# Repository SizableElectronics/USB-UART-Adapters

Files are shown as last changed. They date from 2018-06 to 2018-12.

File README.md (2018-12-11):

# USB-UART-Adapters
We started our UART adapters project because we needed a good insolated adapter. It's somewhat uncommon and not cheap. Time to change that. Check out [sizableelectronics.com/uart-adapters](https://sizableelectronics.com/uart-adapters) for more information. All projekt files and schematics are open source under the **Apache License Version 3.0**.

## Common features of all 3 adapters
* Uses the CP2102 usb to serial ic. Driver is usually not needed on Windows 7/8/10, Mac OS X and Linux.
* All adapters comes with the standard FTDI order of pins on the serial side of the adapter. `GND, NC, VCC, TXD, RXD and NC`. The colors will also match. This layout is the most used layout. But not everyone uses it, please check your layout before pluggin anything in to prevent burning boards.
* All adapters uses the new USB type C connector. Futureprooofness. A type-C to type-A cable is included in the box.

## Short info about the adapters
There are going to exist three different UART adapters in out serie. This is some short info about the induviual adapters below. For more info, check out their's appropriate folders.

* **Serial Dog**
A normal USB to UART/Serial adapter. Delivers 3.3v power to target.

* **Serial Fox**
A USB to UART/Serial adapter that have a wide input range. Both 3.3V and 5V will work. The name Serial Fox comes from the fact that a Fox is very agile, almost like this adapter with the context of voltage levels.

* **Serial Hopper**
A fully insolated USB to UART/Serial adapter. Protects the target from the computer and the other way around in case something bad would to happen to any on them. The name Serial Hopper comes from the fact that a grasshopper jumps really long. Almost like the insolated signals going through the adapter.

## A comparison between the adapters
Serial Dog | Serial Fox | Serial Hopper
--- | --- | ---
USB 2.0 (12 Mbps) | USB 2.0 (12 Mbps) | USB 2.0 (12 Mbps)
USB powers target | Needs power from both ends | Needs power from both ends
3.3V Target levels | 2-6V Target levels | 3.3 or 5v Target levels
Not insulated | Voltlevel insulation | Fully electric insulation
Target Price $11.9 | Target Price $11.9 | Target Price $16.9

## License
Apache License Version 3.0

## Typical BOM
Amount | Part | Description | Pad(s) | Datasheet | Buy Link
--- | --- | --- | --- | --- | ---
1 | CP2102N-A01-GQFN28 | USB to UART IC | U1 | [Github](https://github.com/SizableElectronics/USB-UART-Adapters/raw/master/datasheets/cp2102.pdf) | [LCSC](https://lcsc.com/product-detail/USB_SILICON-LABS_CP2102N-A01-GQFN28_CP2102N-A01-GQFN28_C105167.html) [Digikey](https://www.digikey.se/product-detail/en/silicon-labs/CP2102N-A01-GQFN28/336-3694-ND/6012519)
1 | TYPE-C-31-M-12 | USB Type-C connector | CN1 | -- | [Aliexpress](https://www.aliexpress.com/item/100PCS-LOT-USB-connector-Type-C-3-1-Female-connector-16Pin-SMD-SMT-Type-with-4/32822609480.html) [LCSC](https://lcsc.com/product-detail/USB-Type-C_TYPE-C-31-M-12-Female-16P-SMD_C165948.html)
1 | 1x6 Header | 6-pin, angled, 2.54mm/0.1", smd, female | C1 | -- | [Alibaba](https://www.alibaba.com/product-detail/SMD-0-1-Right-Angle-6_60556277672.html)
1 | USBLC6-2SC6 | USB Protection IC | D1 | -- | [Digikey](https://www.digikey.se/product-detail/en/stmicroelectronics/USBLC6-2SC6/497-5235-1-ND/1121688)
1 | AZ1117H-3.3TRG1  | LDO, Stepdowns for 3V3 | U2 | [Github](https://github.com/SizableElectronics/USB-UART-Adapters/raw/master/datasheets/AZ1117-1139752.pdf) | [Mouser](https://www.mouser.se/ProductDetail/Diodes-Incorporated/AZ1117H-33TRG1?qs=5V6w%252be2aIqa3gA4GjxrsQQ==) [LCSC](https://lcsc.com/product-detail/Low-Dropout-Regulators-LDO_DIODES_AZ1117H-3-3TRG1_AZ1117H-3-3TRG1_C110474.html)
2 | BAT54S | Target protection diods | D2, D3 | -- | [LCSC](https://lcsc.com/product-detail/Schottky-Barrier-Diodes-SBD_NXP_BAT54S_BAT54S-215_C47546.html)
6 | 22R Resistor | 0402 | R1,R2,R5,R6,R7,R8 | -- | [LCSC](https://lcsc.com/product-detail/Chip-Resistor-Surface-Mount_22R-220-5_C93929.html)
1 | 47k5 Resistor | 0402, for config of CP2102N | R3 | -- | [LCSC](https://lcsc.com/product-detail/Chip-Resistor-Surface-Mount-UniOhm_Uniroyal-Elec-0402WGF4752TCE_C25896.html)
1 | 22k1 Resistor | 0402, for config of CP2102N | R4 | -- | [LCSC](https://lcsc.com/product-detail/Chip-Resistor-Surface-Mount-UniOhm_Uniroyal-Elec-0402WGF2212TCE_C43473.html)
3 | 680R Resistor | 0402 | R9,R10,R11 | -- | [LCSC](https://lcsc.com/product-detail/Chip-Resistor-Surface-Mount-UniOhm_Uniroyal-Elec-0402WGJ0681TCE_C25177.html)
1 | 3K3 Resistor  | 0402 | R12 | -- | [LCSC](https://lcsc.com/product-detail/Chip-Resistor-Surface-Mount_3-3KR-332-5_C102983.html)
4 | 100n Capacitor | 0402 | C2,C3,C4,C5 | -- | [LCSC](https://lcsc.com/product-detail/Multilayer-Ceramic-Capacitors-MLCC-SMD-SMT_muRata_GCM155R71C104KA55D_100nF-104-10-16V-Car-level_C85857.html)
1 | 10u Capacitor | 0603 | C6 | -- | [LCSC](https://lcsc.com/product-detail/Multilayer-Ceramic-Capacitors-MLCC-SMD-SMT_10uF-106-20-16V_C109457.html)
1 | 600Ω Inductor | 0603 | L1 | -- | [LCSC](https://lcsc.com/product-detail/Ferrite-Beads-And-Chips_600R-25-1-3A_C97000.html)
1 | Polyfuse | 1206 | F1 | -- | [LCSC](https://lcsc.com/product-detail/Surface-Mount-Fuses_Self-healing-fuse-500mA-15V_C146252.html)
1 | ORANGE LED | TX LED 0603 | D4 | -- | [LCSC](https://lcsc.com/product-detail/_FFC-1608YOXK-600H08_C108553.html)
1 | GREEN LED | POWER LED 0603 | D5 | -- | [LCSC](https://lcsc.com/product-detail/Light-Emitting-Diodes-LED_Emerald-SMDLED-500-1080mcd_C87326.html)
1 | YELLOW LED | RX LED 0603 | D6 | -- | [LCSC](https://lcsc.com/product-detail/_FC-1608YXK-585F08_C89811.html)

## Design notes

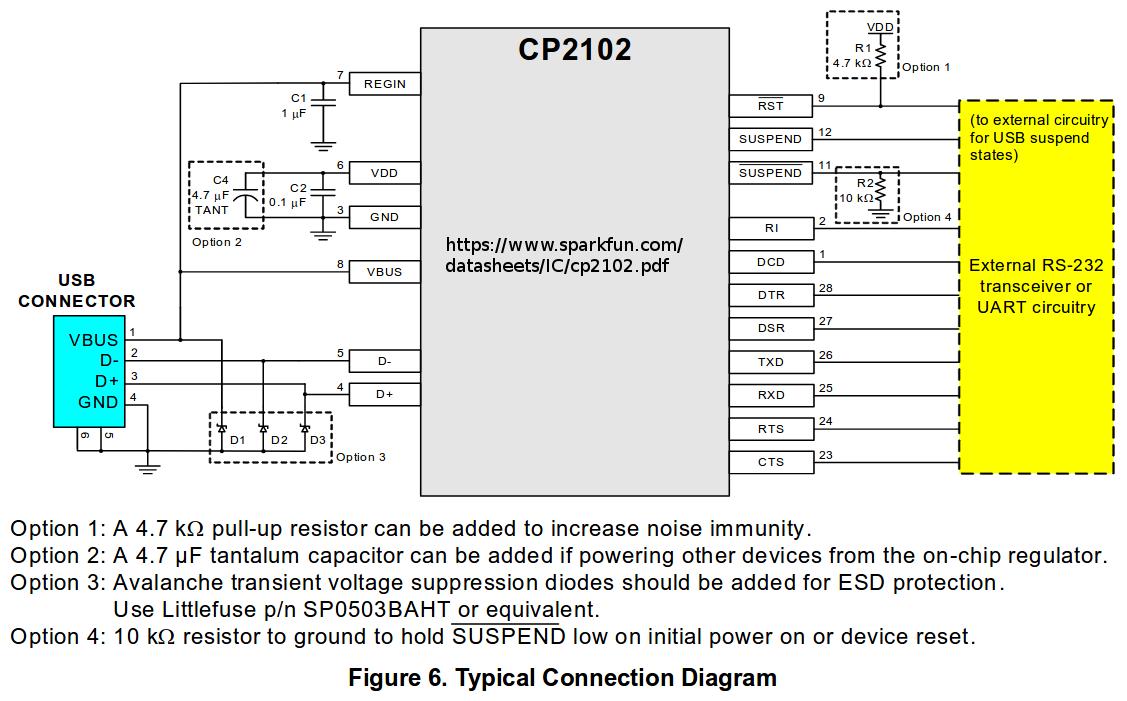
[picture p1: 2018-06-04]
datasheets/cp2102_appl_sch.png

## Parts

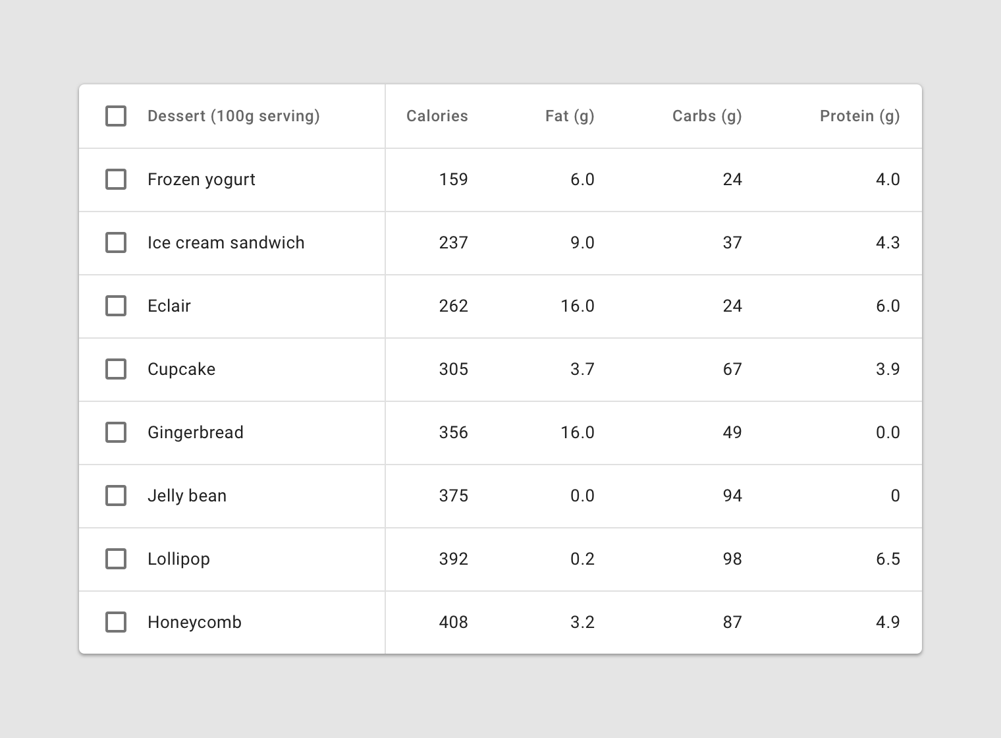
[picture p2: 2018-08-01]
datasheets/components-datatables-structure.png

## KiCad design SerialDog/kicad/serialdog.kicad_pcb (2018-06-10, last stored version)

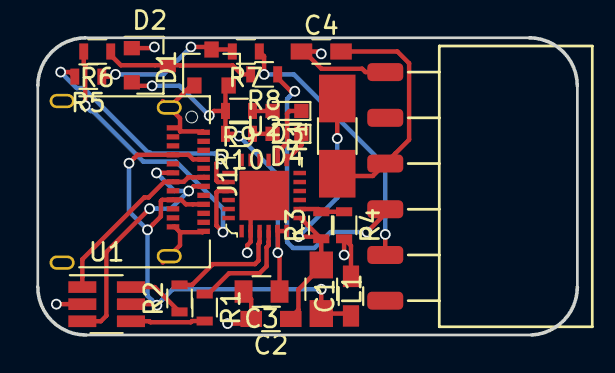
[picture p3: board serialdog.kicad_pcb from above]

Board: 2 copper layers, 30.0 x 16.5 mm, 24 parts (0 on the bottom side), 22 nets.

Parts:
C1, C2, C4: 1u; R_0603_HandSoldering
C3: 1u; C_0805
D1, D2: BAT54S; SOT-23
D3, D4: LED; LED_0603
F1: Polyfuse_Small; Fuse_SMD1206_HandSoldering
J1: Connector:USB_C_Receptacle; USB_C_Receptacle_Amphenol_12401610E4-2A
J2: 1x6_2.54_smd_header; 1x6 header female smd
L1: Ferrite_Bead; R_0805_HandSoldering
R1, R2, R5, R6, R7, R8: 22; R_0603
R3: 22k; R_0603
R4: 47k; R_0603
R9, R10: 1k; R_0603
U1: USBLC6-2SC6; SOT-23-6_Handsoldering
U2: Interface_USB:CP2102N-A01-GQFN24; WQFN-24-1EP_4x4mm

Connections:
/REGIN: C2.1, F1.2, L1.1, R3.1, U2.7
/RX: D1.3, R5.1, R7.2
/TX: D2.3, R6.1, R8.2
/VBUS: C1.1, J1.A4, J1.A9, J1.B4, J1.B9, L1.2, U1.5
/VOUT: C4.2, F1.1, J2.3
GND: C1.2, C2.2, C3.2, C4.1, D1.1, D2.1, J1.A1, J1.A12, J1.B1, J1.B12, J1.S1, J2.1, R4.2, U1.2, U2.2, U2.25
unnamed: C3.1, D1.2, D2.2, R9.2, R10.2, U2.5, U2.6
unnamed: D3.1, U2.14
unnamed: D3.2, R9.1
unnamed: D4.1, U2.13
unnamed: D4.2, R10.1
unnamed: J1.A6, J1.B6, U1.1
unnamed: J1.A7, J1.B7, U1.3
unnamed: J2.4, R8.1
unnamed: J2.5, R7.1
unnamed: R1.1, U2.4
unnamed: R1.2, U1.4
unnamed: R2.1, U1.6
unnamed: R2.2, U2.3
unnamed: R3.2, R4.1, U2.8
unnamed: R5.2, U2.20
unnamed: R6.2, U2.21

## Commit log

2018-06-05 Added a few kicad schematic components
2018-06-05 Started on the serialdog schematic, needs more work
    [serialdog.kicad_pcb, serialdog.sch]
2018-06-07 Tried to start on the pcb layout
    [serialdog.kicad_pcb, serialdog.sch]
2018-06-09 Kicad v5, pcb design started
    [serialdog.kicad_pcb, serialdog.sch]
2018-06-10 Made first pcb layout draft
    [serialdog.kicad_pcb, serialdog.sch]
2018-07-04 Updated the readme and removed old files
    [serialdog.kicad_pcb, serialdog.sch]
2018-08-12 Added Some of the images and gerber/schematic/layout files
2018-08-12 Added schematic to readme file
2018-08-13 Sorted the bom list and added a web version of the nice image
